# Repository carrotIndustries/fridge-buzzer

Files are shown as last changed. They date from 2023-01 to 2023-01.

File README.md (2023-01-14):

Fridge buzzer
=============

Our fridge doesn't give an audible warning when the door is left open 
for too long, so I made this embarrassingly trivial thing to fix this.

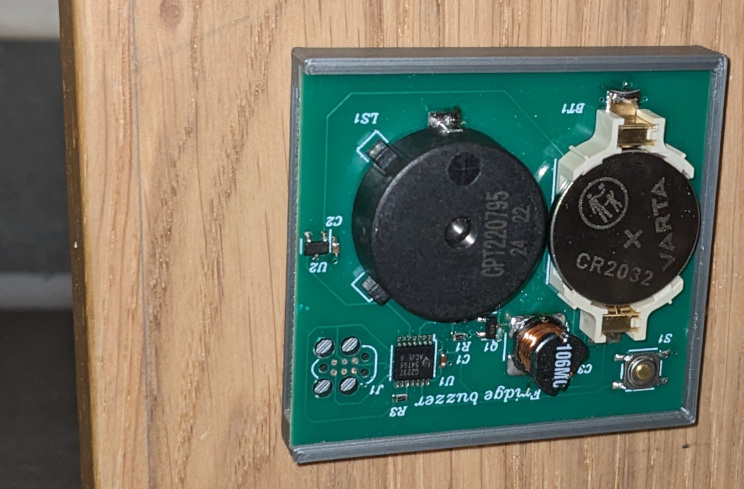
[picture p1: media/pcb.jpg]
Photo of a approx. 5×5cm PCA in a silver 3D printed plastic frame glued onto a wooden door. On the PCB, there's a black piezo buzzer on the left side and CR2032 button cell on the right side. In the lower portion of the PCB, there are a 6-Pin tag-connect footprint, an MSP430 MCU in a TSSOP-14 packa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


# Hardware

[Schematics](fridge-buzzer/output/schematic.pdf)

The fridge buzzer is based on an MSP430G2232 low-power MCU connected to 
a SI7201 hall effect switch and a pizeo buzzer. The whole thing is powered 
from CR2032 button cell.

An inductor is connected in parallel to the piezo buzzer to increase 
its volume.

For programming the MSP430, there's a 6-pin Tag-Connect footprint on 
the board.

As usual, this board is made with [Horizon 
EDA](https://horizon-eda.org/).

# Firmware

The firmware is less than 200 lines of spaghetti-ish C to be compiled 
with msp430-elf-gcc. By making use of the MSP430's sleep modes and 
configuring peripherals the right way, the 
idle power consumption is less than 3&nbsp;µA, resulting in a projected 
battery life of about 9 years on a 235&nbsp;mAh battery.

After inserting the battery, the device is in setup mode for about 25 
seconds and beeps if it detects the magnet. After that, it enters 
normal operation. If the door's been open for longer than 90 seconds, 
it starts beeping in a not-so-annoying low-pitched tone. After 120 
seconds, it starts beeping in a higher pitch. To avoid annoying people 
in case of a malfunction such a fallen off magnet, beeping stops after 
5 minutes.

Pressing the button on the board mutes the beep until the door is 
closed again.

# Mechanical construction

The PCB slides into in a 3D-printed holder that's glued to the fridge door 
with mounting tape. The magnet that actuates the hall-effect switch 
is pressed into a stick that sits in a 3D-printed holder that's glued to the 
fridge cabinet. By adjusting the position of the stick, one can tune 
the sensitivity to make sure a slightly ajar door is detected as open.

All parts were designed in solvespace.

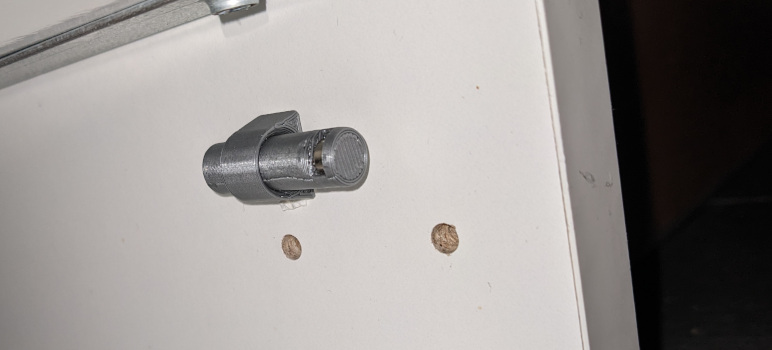
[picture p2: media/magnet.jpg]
Photo of a 3D-printed silver cylindrical stick that sits inside a roughly triangular holder. The holder is glued to the inside of a white cabinet.


# License

Hardware and mechanical parts CERN Open Hardware Licence v1.2, Firmware 
GPLv3

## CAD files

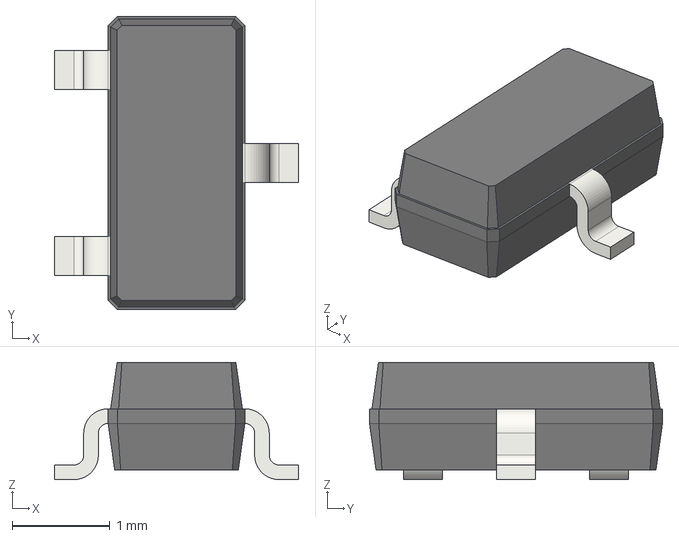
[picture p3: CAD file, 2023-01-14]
fridge-buzzer/pool/3d_models/cache/6d752bc3-29b3-45df-8cf2-1e3aacefbcc6/3d_models/ic/so/SOT-23.step
2.50 x 3.00 x 1.20 mm

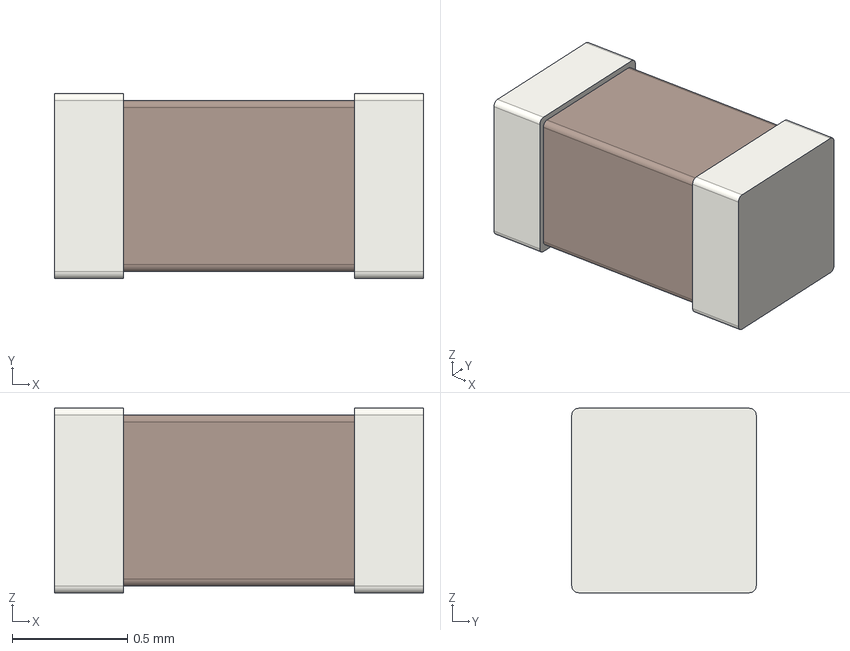
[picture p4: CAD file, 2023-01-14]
fridge-buzzer/pool/3d_models/cache/6d752bc3-29b3-45df-8cf2-1e3aacefbcc6/3d_models/passive/capacitor/C_0603_1608Metric.step
1.60 x 0.8 x 0.8 mm

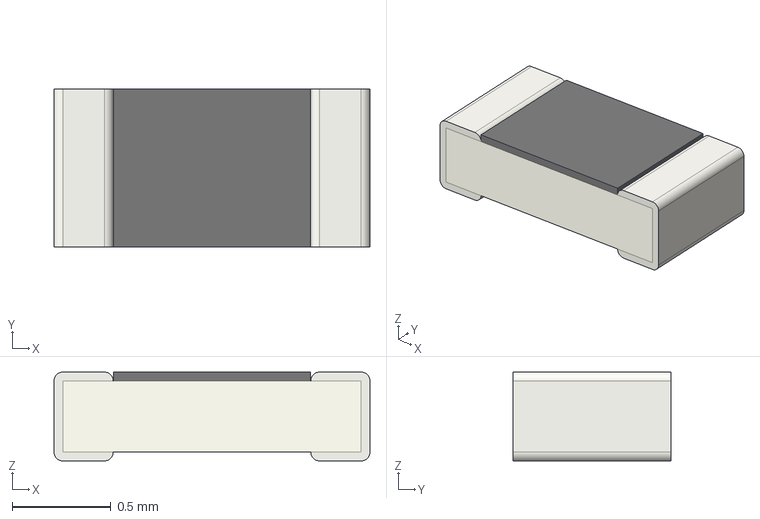
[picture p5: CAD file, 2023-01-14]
fridge-buzzer/pool/3d_models/cache/6d752bc3-29b3-45df-8cf2-1e3aacefbcc6/3d_models/passive/resistor/R_0603_1608Metric.step
1.60 x 0.8 x 0.45 mm

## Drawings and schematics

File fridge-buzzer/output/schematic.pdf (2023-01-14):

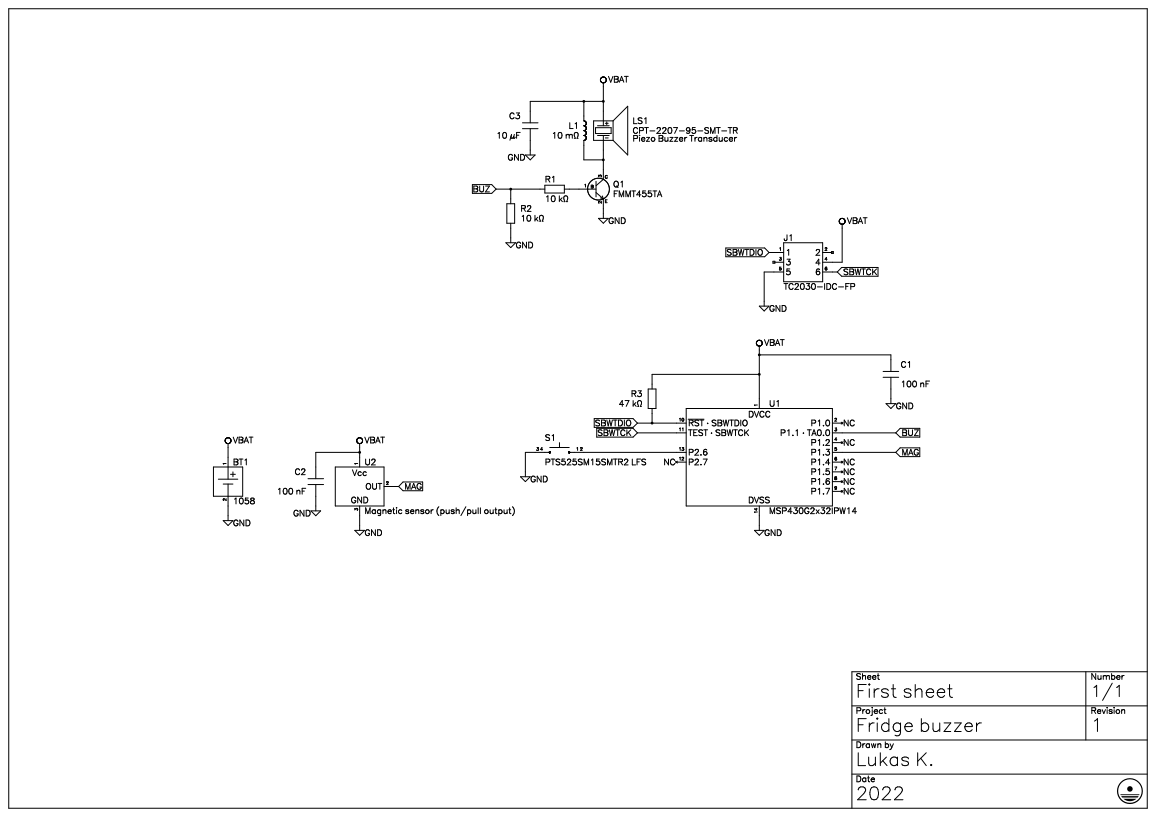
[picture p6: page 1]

GND
Magnetic sensor (push/pull output)

Fridge buzzer | 1
Lukas K.

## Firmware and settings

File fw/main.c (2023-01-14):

#include <msp430.h>
#include <stdint.h>

static volatile uint8_t beep_on = 0;

static void set_beep_freq(uint16_t freq)
{
    beep_on = freq!=0;
    if(freq) {
        P1SEL |= BIT1;
        TACCTL0 = OUTMOD_4;
        //TACCR0 = 150;
        //TACCR0 = 600;
        TACCR0 = freq;
        TACCR1 = 0;
        TACTL = TASSEL_2 | MC_1;
    }
    else {
        P1SEL &= ~BIT1;
        TACCTL0 = OUTMOD_5;
        TACTL = TASSEL_2 | MC_0;
    }
}

static uint8_t beep_on1;
static uint8_t beep_period1;
static uint8_t beep_on2;
static uint8_t beep_period2;
static uint16_t beep_freq;

static uint8_t beep_counter2;
static uint8_t beep_counter1;
static uint8_t beep_once = 0;

static void set_beep(uint8_t on1, uint8_t period1, uint8_t on2, uint8_t period2, uint16_t freq)
{
    beep_on1 = on1;
    beep_period1 = period1;
    beep_on2 = on2;
    beep_period2 = period2;
    beep_freq = freq;
    beep_counter1 = 0;
    beep_counter2 = 0;
    beep_once = 0;
}

static void set_beep_once(uint8_t on1, uint8_t period1, uint8_t on2, uint8_t period2, uint16_t freq)
{
    beep_on1 = on1;
    beep_period1 = period1;
    beep_on2 = on2;
    beep_period2 = period2;
    beep_freq = freq;
    beep_counter1 = 0;
    beep_counter2 = 0;
    beep_once = 1;
}

static void do_beep(void)
{

    //set_beep_freq(beep_freq);
    if(beep_counter1 < beep_on1 && (beep_counter2 < beep_on2)) {
        set_beep_freq(beep_freq);
    }
    else {
        set_beep_freq(0);
    }
    
    if(beep_counter1 < beep_period1) {
        beep_counter1++;
    }
    else {
        beep_counter1 = 0;
        if(beep_counter2 < beep_period2) {
            beep_counter2++;
        }
        else {
            beep_counter2 = 0;
            if(beep_once) {
                beep_on2 = 0;
            }
        }
    }
}

static uint16_t setup_counter = 25*20; //approx 25sec
static uint16_t door_open_counter = 0;
static uint8_t muted = 0;

void __attribute__((interrupt((WDT_VECTOR)))) WDT_ISR(void)
{
    static uint8_t div = 0;
    static uint8_t pin_last;
    
    if(setup_counter) {
        if((P1IN & BIT3) && !(pin_last & BIT3)) {
            set_beep(1, 2, 11, 10, 800); 
        }
        else if(!(P1IN & BIT3) && (pin_last & BIT3))
        {
            set_beep(0,0,0,0,0);
        }
        
        
        if(setup_counter == 1) {
            set_beep_once(5, 4, 3, 10, 150);
        }
        setup_counter--;
    }
    else {

        
        if(!(P1IN & BIT3)) {
            if(door_open_counter != 0xffff)
                door_open_counter++;
            if(!(P2IN & BIT6)) {
                muted = 1;
                set_beep_once(5, 4, 2, 10, 700);
            }
        }
        else {
            if(door_open_counter > 90*20 || muted) 
                set_beep_once(1, 2, 2, 10, 150);
            door_open_counter = 0;
            muted = 0;
            //set_beep(0,0,0,0,0);
        }
        
        if(door_open_counter == 90*20 && !muted) {
            set_beep(1, 4, 3, 15, 600);
        }
        if(door_open_counter == 120*20 && !muted) {
            set_beep(2, 4, 10, 20, 150);
        }
        if(door_open_counter == 5*60*20) {
            set_beep(0,0,0,0,0);
        }
        
        
    }
    
    pin_last = P1IN;
    do_beep();
    div = (div+1)%4;
    if(beep_on)
        LPM3_EXIT;
}

int main(void)
{
    WDTCTL = WDTPW | WDTHOLD;
    BCSCTL3 = LFXT1S_2;
    
    P1DIR |= BIT1 | BIT0 | BIT2 | BIT4 | BIT5 | BIT6 | BIT7;
    P2DIR = ~BIT6;
    P2REN |= BIT6;
    P1OUT = 0;
    P2OUT = BIT6;
    
    P2SEL &= ~BIT7;
    
    WDTCTL = WDTPW | WDTTMSEL | WDTCNTCL | WDTSSEL |  WDTIS1;
    IE1 |= WDTIE;
    __eint();
    set_beep_once(1, 4, 1, 10, 150);
    while(1) {
        if(!beep_on)
            LPM3;
    }

    return 0;
}

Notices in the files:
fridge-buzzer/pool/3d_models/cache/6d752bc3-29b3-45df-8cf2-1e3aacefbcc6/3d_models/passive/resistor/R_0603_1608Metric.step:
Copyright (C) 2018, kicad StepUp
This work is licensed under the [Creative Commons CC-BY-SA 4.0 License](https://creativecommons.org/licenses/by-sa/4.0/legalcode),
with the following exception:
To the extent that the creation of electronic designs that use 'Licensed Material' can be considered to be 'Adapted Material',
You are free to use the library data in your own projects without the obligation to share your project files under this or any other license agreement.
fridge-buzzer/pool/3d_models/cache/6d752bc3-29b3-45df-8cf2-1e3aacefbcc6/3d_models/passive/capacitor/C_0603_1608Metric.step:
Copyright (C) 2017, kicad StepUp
